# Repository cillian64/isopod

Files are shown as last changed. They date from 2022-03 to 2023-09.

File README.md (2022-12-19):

# ISOPOD

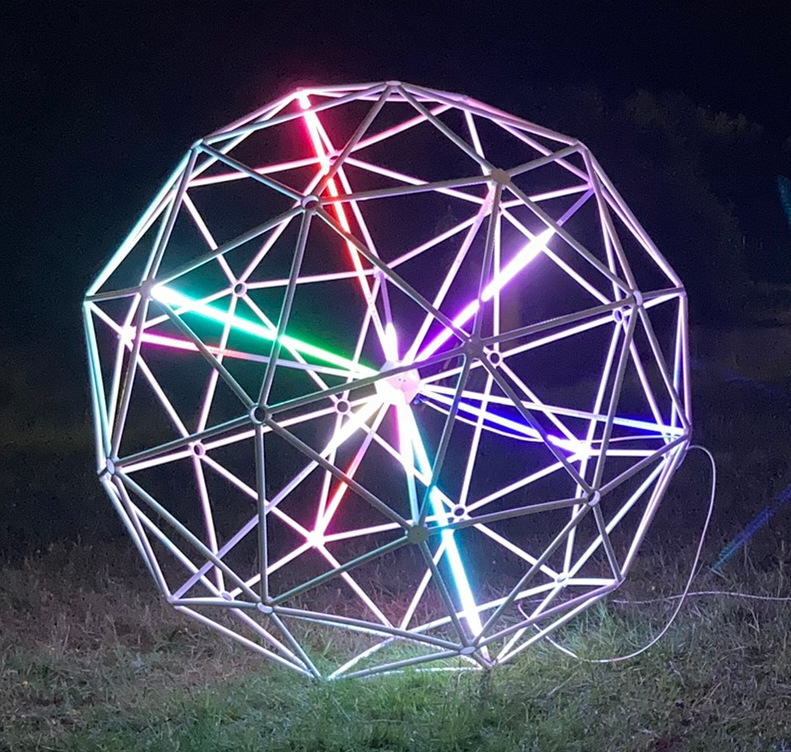
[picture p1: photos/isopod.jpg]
A photo of ISOPOD with a colourful pattern


ISOPOD is a mobile interactive LED sculpture based on a 2.1m geodesic
isocahedron.  It was displayed at [EMF 2022](https://www.emfcamp.org/).

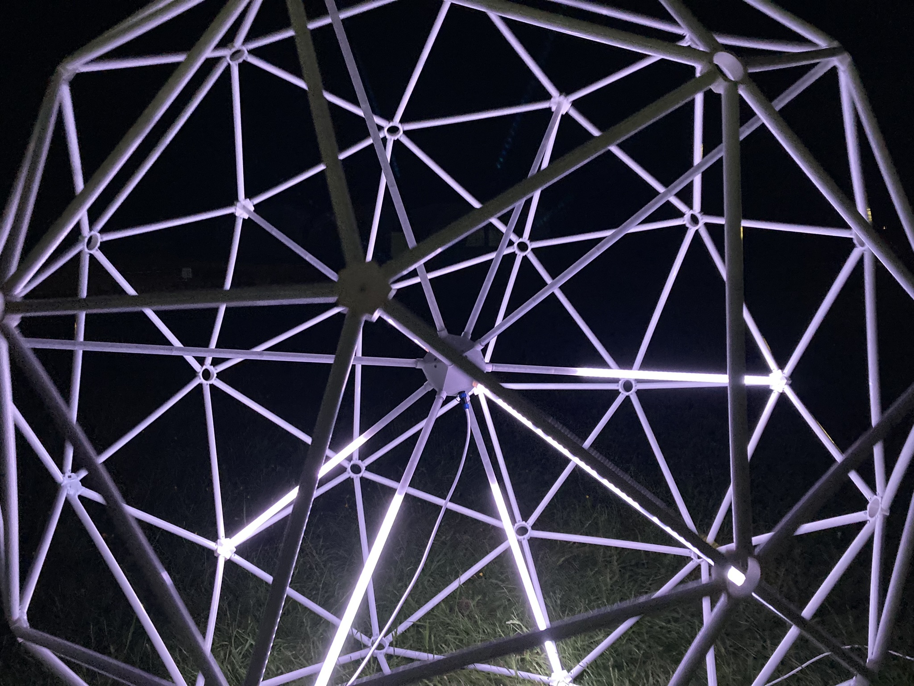
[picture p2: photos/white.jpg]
A close-up photo of ISOPOD's structure


The outer shell is a 2V geodesic isocahedron made from custom-designed 3d
printed hubs and plastic water pipe.  The core is a regular icosahedron.  12
LED tubes connect to the core's vertices, each made from frosted acrylic tube
and containing a WS2812b addressable LED strip.

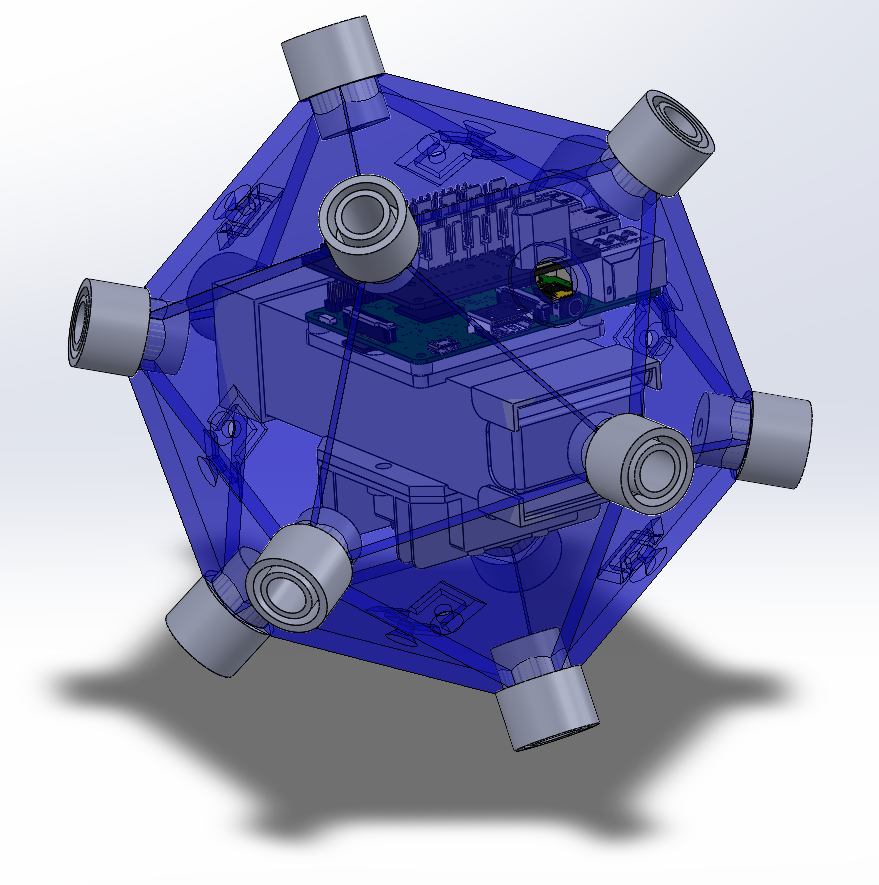
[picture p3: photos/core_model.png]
A 3d model of the ISOPOD core and components


The core contains a battery, control electronics, and DC-DC converters.  ISOPOD
is controlled by a Raspberry Pi running software written in Rust.  A custom PCB
mounted on the Pi connects to the battery, DC-DC converters, and LED strips and
adds a battery fuel gauge, GPS module, and 9-axis IMU (accelerometer,
gyroscope, and magnetometer).

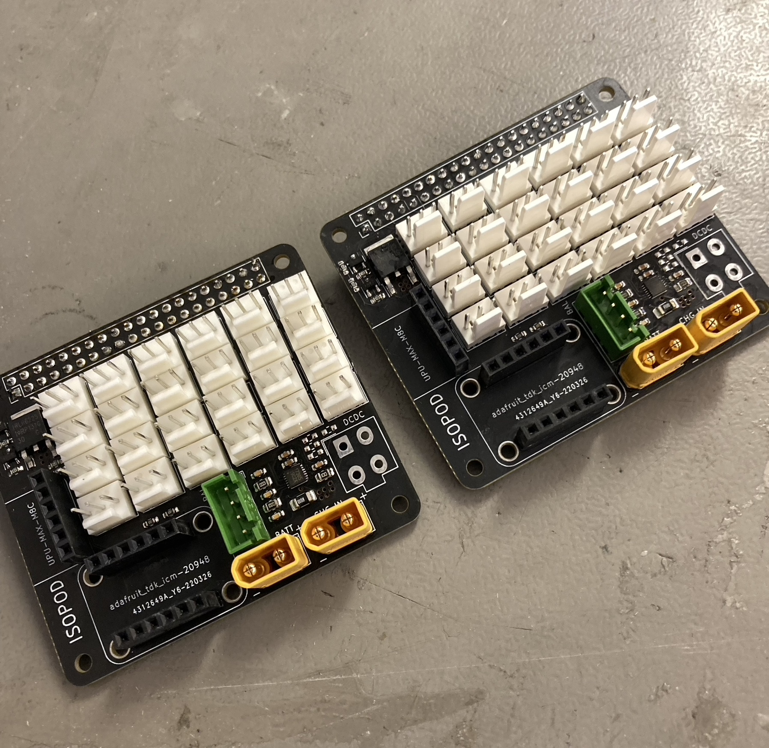
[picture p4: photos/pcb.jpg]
A photo of the ISOPOD PCBs


ISOPOD was displayed at EMF 2022 with a tether cable (to extend battery life
and avoid it rolling downhill into the lake) but is designed to be totally
wireless, reporting its position and status over Wi-Fi to a backend server.

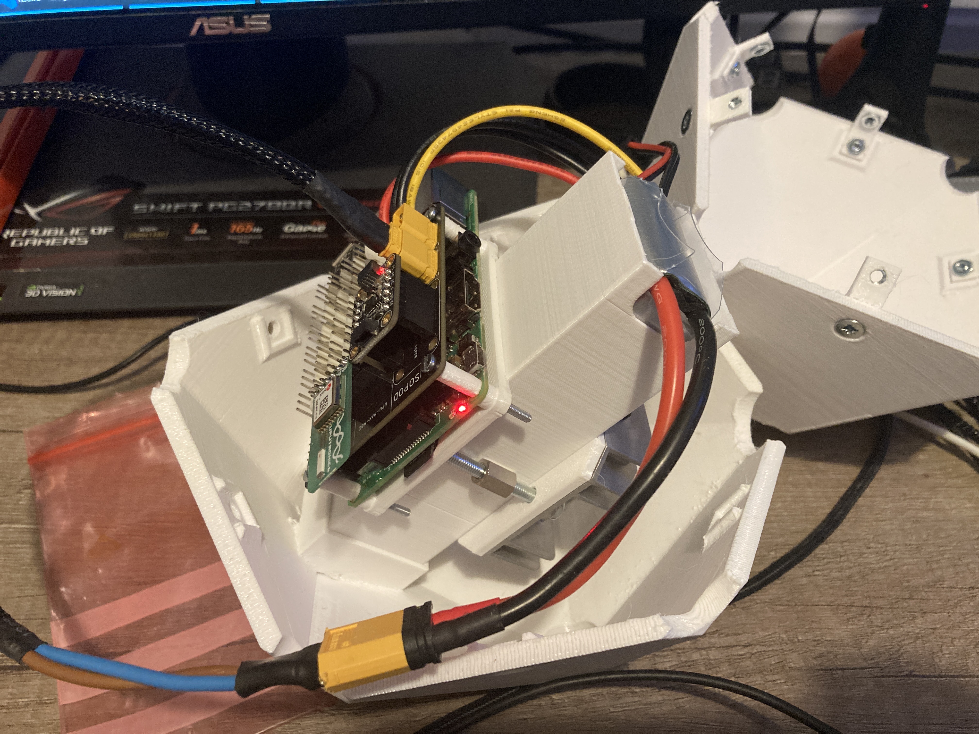
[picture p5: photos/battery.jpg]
A photo of the battery connection


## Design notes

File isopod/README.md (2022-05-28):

# ISOPOD firmware

This is the firmware for Isopod.

## Simulator / visualiser
Normally the software is built to run on the raspberry pi hardware using the
`build_and_remote_run.sh` script.  However for pattern development it's
possible to run the software on a PC (with no sensor or GPS or LED access)
and view the LED status using the web visualiser.  To run the software on
a PC, run, on linux:

```cargo run --target=x86_64-unknown-linux-gnu --no-default-features --bin isopod```

Or on MacOS:

```cargo run --target=x86_64-apple-darwin --no-default-features --bin isopod```

Then open the [sim/sim.html](sim/sim.html) file in your browser.  The
visualiser can be connected to either the actual raspberry pi or to the local
simulator by toggling the "local sim" / "hardware" buttons in the top left
corner.

## Architecture
### Firmware functions
* Collect location data from GPS peripheral over UART
* Collect movement/orientation data from IMU over I2C
* Collect battery level from fuel gauge over I2C
* Control addressable LEDs via PWM and GPIO
* Report location to a remote server over HTTPS over Wi-Fi

### LED control algorithm
The LED-control logic is roughly as follows:
* If the battery level is low then do a low-power pattern:
  * Every three seconds flash all LEDs briefly red and otherwise off.
* Otherwise, if we are currently moving, illuminate all the LEDs with a hue
  which depends on current orientation, full saturation, and a value depending
  on gyro rate.
* Otherwise, if we are currently stationary but have moved within the past few
  minutes, do a pattern depending on our current orientation.  Ideas:
  * Smooth rainbow colour fading
  * Random sparkling
  * Radial rainfall with colour spots mixed in
  * TODO: more ideas here
* Otherwise, if we have not moved in a couple of minutes then do the idle
  pattern:
  * Every second, pulse red from the centre out

### Architecture
The firmware is architected roughly as follows:
* GPS, IMU, and battery level data are collected by separate threads
* Their data is written into shared structures which are protected by mutexes
* The main thread implements application logic - it reads from the sensor
  structures and writes to the LED control structure.
* An LED control thread determines the desired LED state, and writes to the
  PWM and GPIO peripherals to control the LEDs.
* A location reporting thread periodically reports the location over HTTPS
  over Wi-Fi.

## Setup

Install rust with default setup:

`curl --proto '=https' --tlsv1.2 -sSf https://sh.rustup.rs | sh`

Install some more things, some only required for cross-compilation

sudo apt install llvm build-essential gcc-arm-linux-gnueabihf libclang-dev gcc-multilib

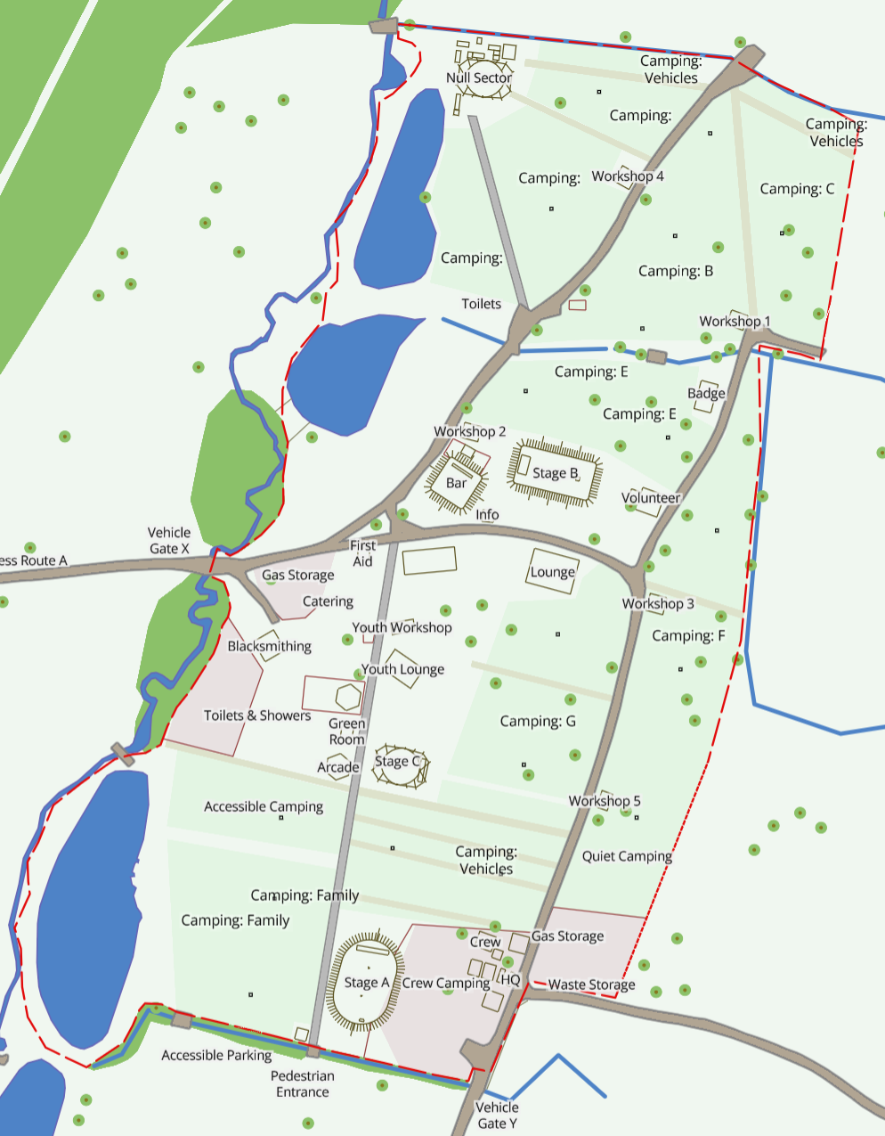
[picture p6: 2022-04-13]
backend/emf_base_map.png

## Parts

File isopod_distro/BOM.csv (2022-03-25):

Comment | Designator | Footprint | LCSC | Qty/board | Qty
BAL | J29 | JST_XH_B4B-XH-AM_1x04_P2.50mm_Vertical | C594233 | 1 | 2
Raspberry_Pi_2_3 | J30 | PinHeader_2x20_P2.54mm_Vertical | C132132 | 1 | 2
100n | C4 | C_0603_1608Metric_Pad1.08x0.95mm_HandSolder | C14663 | 1 | 5
0.01R | R4 | R_1206_3216Metric_Pad1.30x1.75mm_HandSolder | C154635 | 1 | 5
1n | C3,C5,C6 | C_0603_1608Metric_Pad1.08x0.95mm_HandSolder | C1588 | 3 | 10
470n | C1,C2 | C_0603_1608Metric_Pad1.08x0.95mm_HandSolder | C1623 | 2 | 10
100 | R2,R3 | R_0805_2012Metric_Pad1.20x1.40mm_HandSolder | C17408 | 2 | 10
10 | R1 | R_0805_2012Metric_Pad1.20x1.40mm_HandSolder | C17734 | 1 | 5
150 | R7,R8 | R_0603_1608Metric_Pad0.98x0.95mm_HandSolder | C22808 | 2 | 10
2R2 | R5 | R_0603_1608Metric_Pad0.98x0.95mm_HandSolder | C22939 | 1 | 5
10k | R10,R11,R12,R6,R9 | R_0603_1608Metric_Pad0.98x0.95mm_HandSolder | C23192 | 5 | 15
MAX17205 | U1 | TDFN-14-1EP_3x3mm_P0.4mm_EP1.78x2.35mm | C401140 | 1 | 3
BSS138 | Q2,Q3 | SOT-23 | C75547 | 2 | 10
DCDC | J8 | Molex_Mini-Fit_Jr_5566-04A_2x02_P4.20mm_Vertical | C47233 | 1 | 5
IN 1 | J10,J11,J12,J13,J14,J15,J17,J18,J19,J2,J20,J21,J22,J23,J24,J25,J26,J27,J28,J3,J4,J5,J6,J7 | Molex_KK-254_AE-6410-03A_1x03_P2.54mm_Vertical | C706936 | 24 | 24
CHG_IN | J1,J16 | AMASS_XT30U-M_1x02_P5.0mm_Vertical | C99101 | 2 | 2

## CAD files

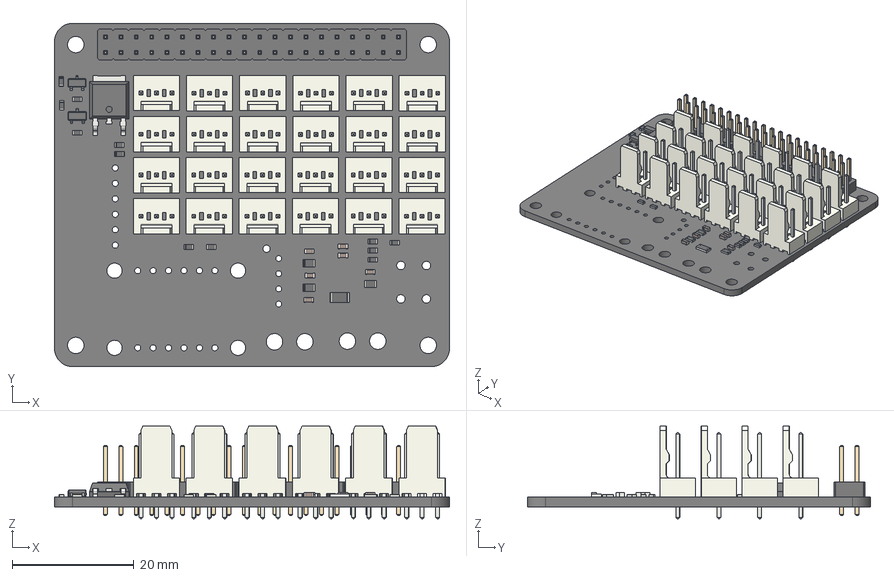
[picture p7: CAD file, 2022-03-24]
isopod_distro/isopod_distro.step
65.0 x 56.5 x 15.3 mm
Pcb_4663
Q2_SOT_23_13de3de3c2ef x 2
R11_R_0603_1608Metric_2da430bc9cf8 x 12
C1_C_0603_1608Metric_94d6544a8366 x 6
J23_Molex_AE_6410_03A_57582ce10efd x 24
J30_PinHeader_2x20_P254mm_Vertical_b2ee337b9778
R4_R_1206_3216Metric_e61873b6a125
R1_R_0805_2012Metric_dd68c0426109 x 3
Q1_TO_252_2_08bba05e86ff

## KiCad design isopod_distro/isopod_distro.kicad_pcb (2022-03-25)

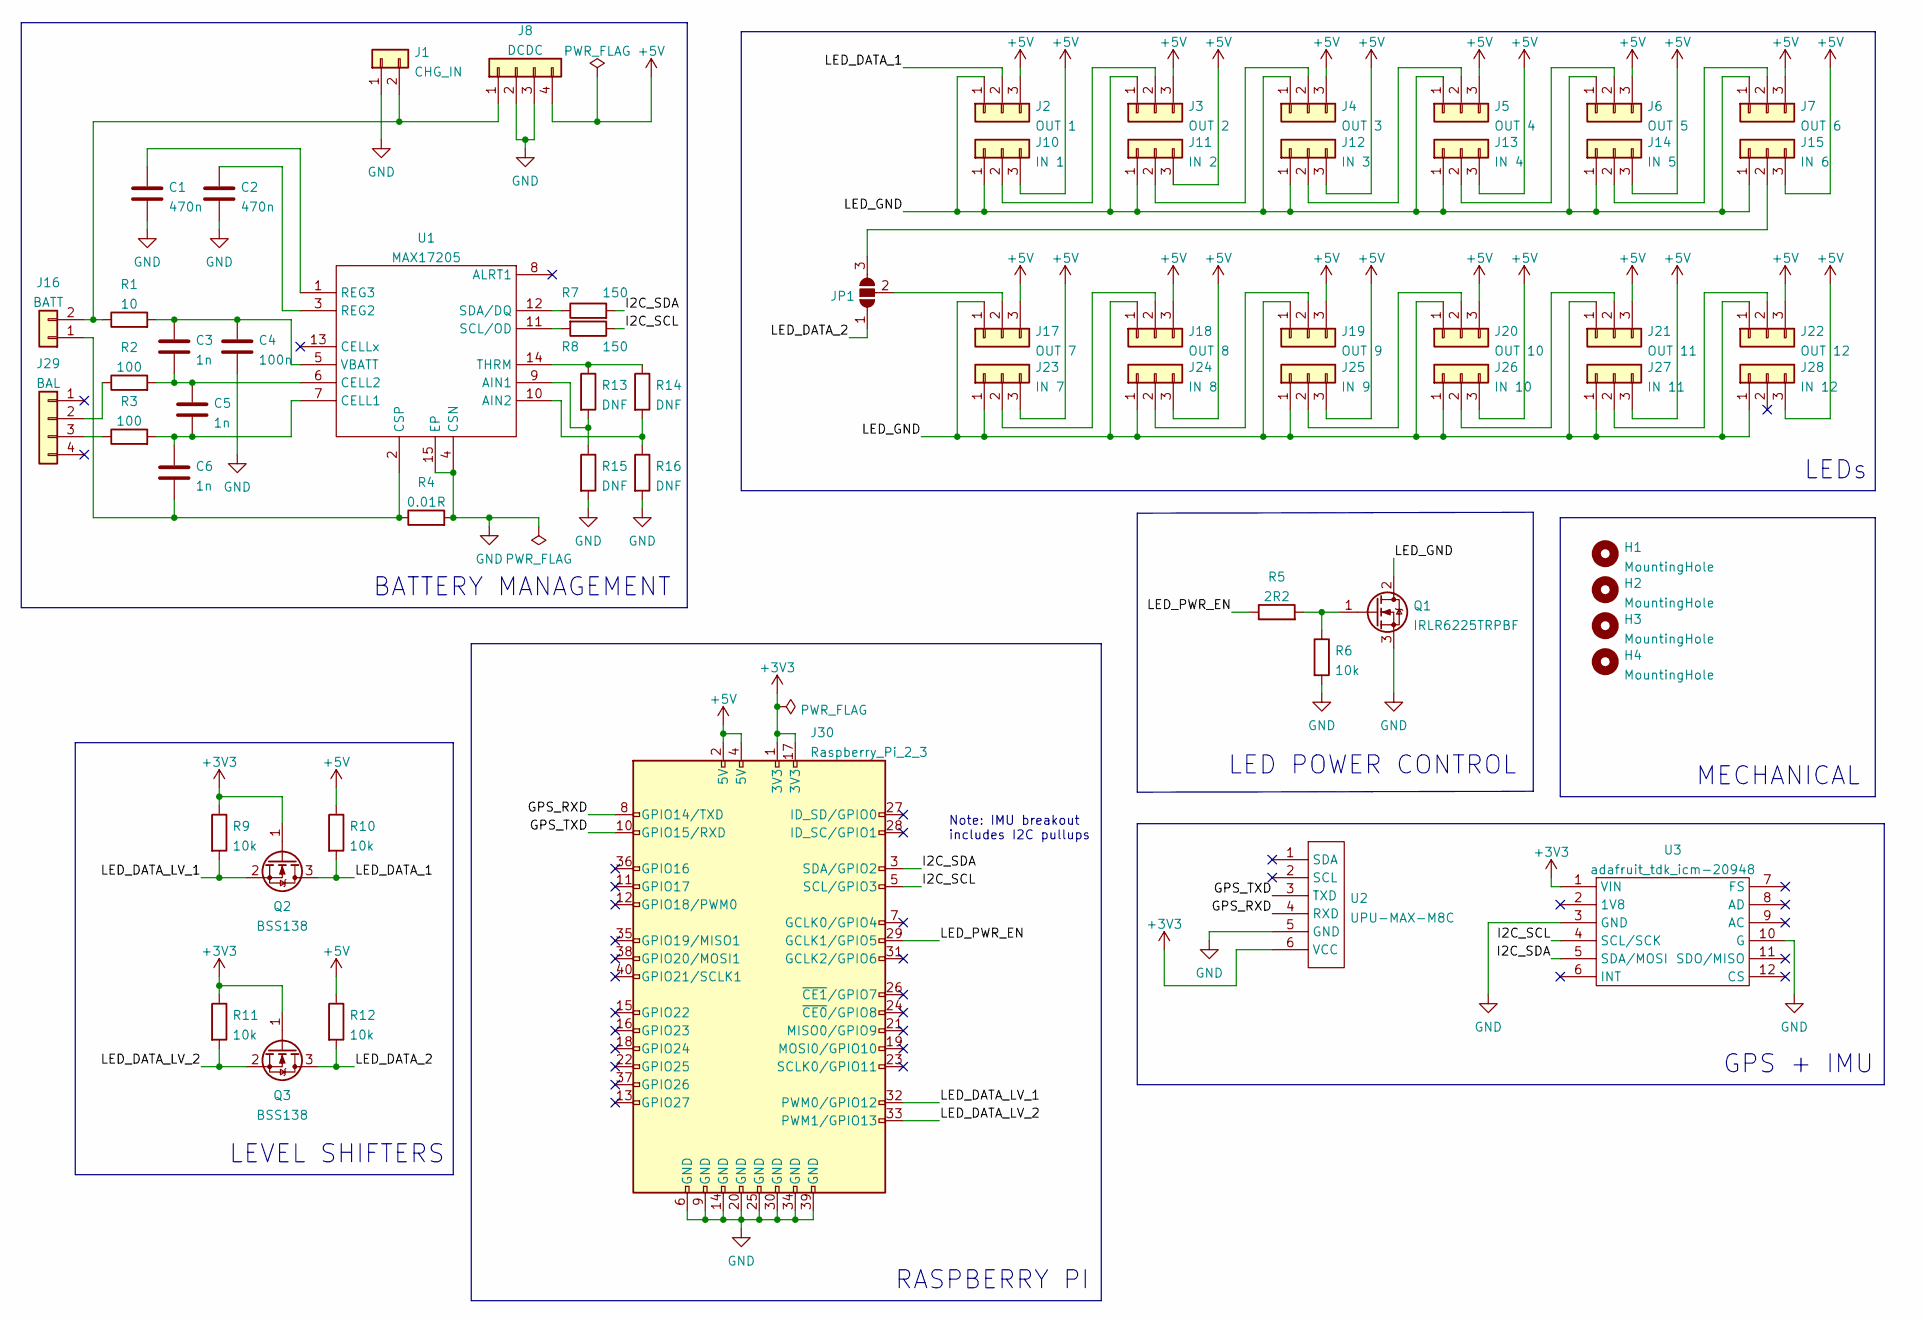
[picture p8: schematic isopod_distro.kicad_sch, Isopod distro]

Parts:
C1, C2: 470n; C_0603_1608Metric_Pad1.08x0.95mm_HandSolder
C3, C5, C6: 1n; C_0603_1608Metric_Pad1.08x0.95mm_HandSolder
C4: 100n; C_0603_1608Metric_Pad1.08x0.95mm_HandSolder
H1, H2, H3, H4: MountingHole; MountingHole_2.7mm
J1: CHG_IN; AMASS_XT30U-M_1x02_P5.0mm_Vertical
J2: OUT 1; Molex_KK-254_AE-6410-03A_1x03_P2.54mm_Vertical
J3: OUT 2; Molex_KK-254_AE-6410-03A_1x03_P2.54mm_Vertical
J4: OUT 3; Molex_KK-254_AE-6410-03A_1x03_P2.54mm_Vertical
J5: OUT 4; Molex_KK-254_AE-6410-03A_1x03_P2.54mm_Vertical
J6: OUT 5; Molex_KK-254_AE-6410-03A_1x03_P2.54mm_Vertical
J7: OUT 6; Molex_KK-254_AE-6410-03A_1x03_P2.54mm_Vertical
J8: DCDC; Molex_Mini-Fit_Jr_5566-04A_2x02_P4.20mm_Vertical
J10: IN 1; Molex_KK-254_AE-6410-03A_1x03_P2.54mm_Vertical
J11: IN 2; Molex_KK-254_AE-6410-03A_1x03_P2.54mm_Vertical
J12: IN 3; Molex_KK-254_AE-6410-03A_1x03_P2.54mm_Vertical
J13: IN 4; Molex_KK-254_AE-6410-03A_1x03_P2.54mm_Vertical
J14: IN 5; Molex_KK-254_AE-6410-03A_1x03_P2.54mm_Vertical
J15: IN 6; Molex_KK-254_AE-6410-03A_1x03_P2.54mm_Vertical
J16: BATT; AMASS_XT30U-M_1x02_P5.0mm_Vertical
J17: OUT 7; Molex_KK-254_AE-6410-03A_1x03_P2.54mm_Vertical
J18: OUT 8; Molex_KK-254_AE-6410-03A_1x03_P2.54mm_Vertical
J19: OUT 9; Molex_KK-254_AE-6410-03A_1x03_P2.54mm_Vertical
J20: OUT 10; Molex_KK-254_AE-6410-03A_1x03_P2.54mm_Vertical
J21: OUT 11; Molex_KK-254_AE-6410-03A_1x03_P2.54mm_Vertical
J22: OUT 12; Molex_KK-254_AE-6410-03A_1x03_P2.54mm_Vertical
J23: IN 7; Molex_KK-254_AE-6410-03A_1x03_P2.54mm_Vertical
J24: IN 8; Molex_KK-254_AE-6410-03A_1x03_P2.54mm_Vertical
J25: IN 9; Molex_KK-254_AE-6410-03A_1x03_P2.54mm_Vertical
J26: IN 10; Molex_KK-254_AE-6410-03A_1x03_P2.54mm_Vertical
J27: IN 11; Molex_KK-254_AE-6410-03A_1x03_P2.54mm_Vertical
J28: IN 12; Molex_KK-254_AE-6410-03A_1x03_P2.54mm_Vertical
J29: BAL; JST_XH_B4B-XH-AM_1x04_P2.50mm_Vertical
J30: Raspberry_Pi_2_3; PinHeader_2x20_P2.54mm_Vertical
JP1: SolderJumper_3_Open; SolderJumper-3_P1.3mm_Bridged12_RoundedPad1.0x1.5mm
Q1: IRLR6225TRPBF; TO-252-2; Farnell 2726021
Q2, Q3: BSS138; SOT-23
R1: 10; R_0805_2012Metric_Pad1.20x1.40mm_HandSolder
R2, R3: 100; R_0805_2012Metric_Pad1.20x1.40mm_HandSolder
R4: 0.01R; R_1206_3216Metric_Pad1.30x1.75mm_HandSolder
R5: 2R2; R_0603_1608Metric_Pad0.98x0.95mm_HandSolder
R6, R9, R10, R11, R12: 10k; R_0603_1608Metric_Pad0.98x0.95mm_HandSolder
R7, R8: 150; R_0603_1608Metric_Pad0.98x0.95mm_HandSolder
R13, R14, R15, R16: DNF; R_0603_1608Metric_Pad0.98x0.95mm_HandSolder
U1: MAX17205; TDFN-14-1EP_3x3mm_P0.4mm_EP1.78x2.35mm; Farnell 3404585
U2: UPU-MAX-M8C; upu-max-m8c
U3: adafruit_tdk_icm-20948; adafruit-tdk-icm-20948

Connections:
+3V3: J30.1 (3V3), J30.17 (3V3), Q2.1 (G), Q3.1 (G), R9.1, R11.1, U2.6 (VCC), U3.1 (VIN)
+5V: J2.3, J3.3, J4.3, J5.3, J6.3, J7.3, J8.4, J10.3, J11.3, J12.3, J13.3, J14.3, J15.3, J17.3, J18.3, J19.3, J20.3, J21.3, J22.3, J23.3, J24.3, J25.3, J26.3, J27.3, J28.3, J30.2 (5V), J30.4 (5V), R10.1, R12.1
/GPS_RXD: J30.8 (GPIO14/TXD), U2.4 (RXD)
/GPS_TXD: J30.10 (GPIO15/RXD), U2.3 (TXD)
/I2C_SCL: J30.5 (SCL/GPIO3), R8.1, U3.4 (SCL/SCK)
/I2C_SDA: J30.3 (SDA/GPIO2), R7.2, U3.5 (SDA/MOSI)
/LED_DATA_1: J2.2, Q2.3 (D), R10.2
/LED_DATA_2: JP1.1 (A), Q3.3 (D), R12.2
/LED_DATA_LV_1: J30.32 (PWM0/GPIO12), Q2.2 (S), R9.2
/LED_DATA_LV_2: J30.33 (PWM1/GPIO13), Q3.2 (S), R11.2
/LED_GND: J2.1, J3.1, J4.1, J5.1, J6.1, J7.1, J10.1, J11.1, J12.1, J13.1, J14.1, J15.1, J17.1, J18.1, J19.1, J20.1, J21.1, J22.1, J23.1, J24.1, J25.1, J26.1, J27.1, J28.1, Q1.2 (D)
/LED_PWR_EN: J30.29 (GCLK1/GPIO5), R5.1
GND: C1.2, C2.2, C4.2, J1.1, J8.2, J8.3, J30.6 (GND), J30.9 (GND), J30.14 (GND), J30.20 (GND), J30.25 (GND), J30.30 (GND), J30.34 (GND), J30.39 (GND), Q1.3 (S), R4.2, R6.2, R15.2, R16.2, U1.4 (CSN), U1.15 (EP), U2.5 (GND), U3.3 (GND), U3.10 (G)
unnamed: C1.1, U1.1 (REG3)
unnamed: C2.1, U1.3 (REG2)
unnamed: C3.1, C4.1, R1.2, U1.5 (VBATT)
unnamed: C3.2, C5.1, R2.2, U1.6 (CELL2)
unnamed: C5.2, C6.1, R3.2, U1.7 (CELL1)
unnamed: C6.2, J16.1, R4.1, U1.2 (CSP)
unnamed: J1.2, J8.1, J16.2, R1.1
unnamed: J3.2, J10.2
unnamed: J4.2, J11.2
unnamed: J5.2, J12.2
unnamed: J6.2, J13.2
unnamed: J7.2, J14.2
unnamed: J15.2, JP1.3 (B)
unnamed: J17.2, JP1.2 (C)
unnamed: J18.2, J23.2
unnamed: J19.2, J24.2
unnamed: J20.2, J25.2
unnamed: J21.2, J26.2
unnamed: J22.2, J27.2
unnamed: J29.2, R2.1
unnamed: J29.3, R3.1
unnamed: Q1.1 (G), R5.2, R6.1
unnamed: R7.1, U1.12 (SDA/DQ)
unnamed: R8.2, U1.11 (SCL/OD)
unnamed: R13.1, R14.1, U1.14 (THRM)
unnamed: R13.2, R15.1, U1.9 (AIN1)
unnamed: R14.2, R16.1, U1.10 (AIN2)

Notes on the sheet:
LED POWER CONTROL
BATTERY MANAGEMENT
LEVEL SHIFTERS
LEDs
MECHANICAL
GPS + IMU
RASPBERRY PI
Note: IMU breakout includes I2C pullups

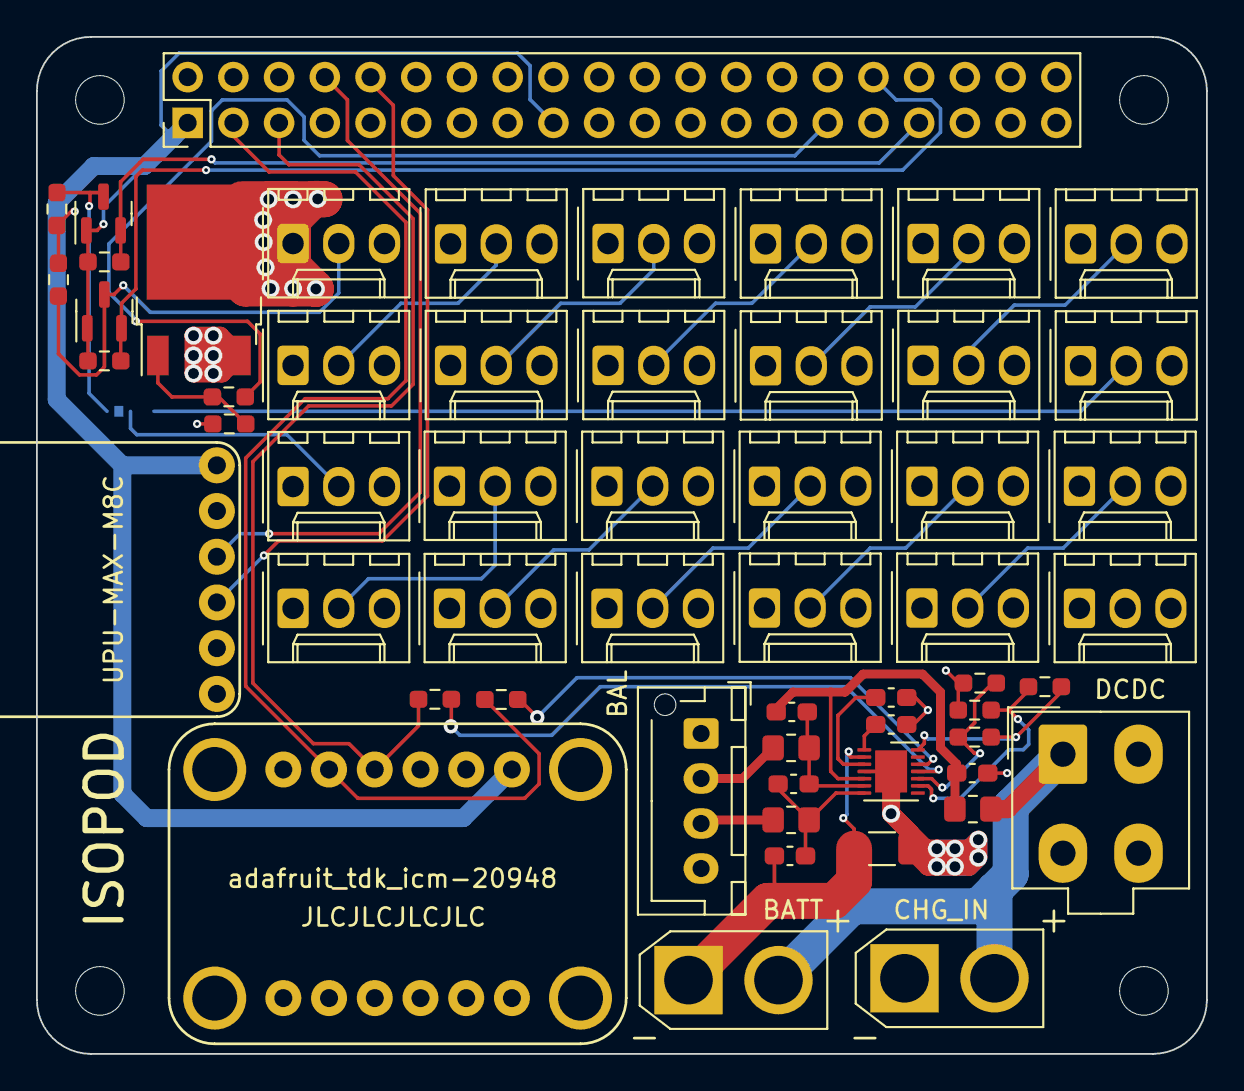
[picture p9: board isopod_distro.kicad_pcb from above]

Board: 4 copper layers, 65.0 x 56.5 mm, 62 parts (1 on the bottom side), 40 nets.

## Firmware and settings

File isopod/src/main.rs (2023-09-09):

//! Initialises and starts up worker threads to do the actual work.

use anyhow::Result;
use config::Config;
use lazy_static::lazy_static;
#[cfg(feature = "hardware")]
use rppal::gpio::Gpio;
#[cfg(feature = "hardware")]
use rppal::i2c::I2c;
#[cfg(feature = "hardware")]
use std::fs::File;
#[cfg(feature = "hardware")]
use std::sync::Arc;
use std::thread;
use std::time;

mod common_structs;
#[cfg(feature = "hardware")]
mod gps;
#[cfg(feature = "hardware")]
mod i2c;
#[cfg(feature = "hardware")]
mod led;
mod pattern_manager;
mod patterns;
#[cfg(feature = "hardware")]
mod reporter;
mod temperature;
mod control_server;
#[cfg(not(feature = "hardware"))]
use common_structs::ImuReadings;

pub const LEDS_PER_SPINE: usize = 59;
pub const SPINES: usize = 12;

lazy_static! {
    static ref SETTINGS: Config = Config::builder()
        .add_source(config::File::with_name("settings"))
        .build()
        .unwrap();
}

// If bluetooth is enabled then the raspberry pi serial port is
// /dev/ttyS0.  If bluetooth is disabled then /dev/ttyAMA0 is used.
#[cfg(feature = "hardware")]
const SERIAL_PORT: &str = "/dev/ttyS0";

#[cfg(feature = "hardware")]
fn main() -> Result<()> {
    println!("Hello, world!");

    println!("Setting up raw peripherals...");
    println!("Setting up GPIO...");
    let gpio = Gpio::new()?;
    println!("Setting up I2C...");
    let i2c = I2c::new()?;
    println!("Setting up GPS...");
    let file = File::open(SERIAL_PORT)?;
    let reader = std::io::BufReader::new(file);
    println!("Peripherals initialised okay!");

    println!("Setting up peripheral controllers...");
    println!("Setting up I2C peripherals controller...");
    let i2cperiphs = Arc::new(i2c::I2cPeriphs::new(i2c));
    println!("Setting up LED controller...");
    let mut led = led::Led::new(gpio);
    println!("Setting up GPS controller...");
    let gps = Arc::new(gps::Gps::new(reader));
    println!("Peripheral drivers initialised okay!");

    if SETTINGS.get("do_startup_tests")? {
        println!("Doing start-up tests...");
        gps.test()?;
        led.test()?;
        i2cperiphs.test()?;
        println!("Start-up tests look good!");
    } else {
        println!("Skipping start-up tests.");
    }

    println!("Starting worker threads...");
    led.start_thread();
    i2cperiphs.clone().start_thread();
    gps.clone().start_thread();
    let mut reporter = reporter::Reporter::new();

    control_server::start_server();
    println!("Worker threads started.");

    let mut pattern_manager = pattern_manager::PatternManager::new();

    let delay_ms = 1000 / SETTINGS.get::<u64>("fps")?;

    let mut last_report = time::Instant::now();
    let report_interval = SETTINGS.get::<u64>("reporter_interval")?;

    loop {
        // Read latest sensor values
        let gps_fix = gps.get();
        let imu_readings = i2cperiphs.get_imu();
        let battery_readings = i2cperiphs.get_battery();

        // Step pattern and update LEDs
        let led_state = pattern_manager.step(&gps_fix, &imu_readings);
        led.led_update(led_state)?;

        // Send a report if necessary
        let now = time::Instant::now();
        if report_interval > 0 && (now - last_report).as_secs() > report_interval {
            last_report = now;
            // Ignore report errors
            let _res = reporter.send(gps_fix, battery_readings);
        }

        // Sleep until time for the next pattern step
        thread::sleep(time::Duration::from_millis(delay_ms));
    }
}

#[cfg(not(feature = "hardware"))]
fn main() -> Result<()> {
    println!("Hello, world!");
    println!("Simulator mode: skipping setup and self-tests");

    println!("Starting worker threads...");
    // In simulator mode, always enable ws server regardless of config
    let ws = ws_server::WsServer::start_server();
    println!("Worker threads started.");

    let mut pattern_manager = pattern_manager::PatternManager::new();

    let delay_ms = 1000 / SETTINGS.get::<u64>("fps")?;

    loop {
        // Mock up sensor values
        let gps_fix = None;
        let imu_readings = ImuReadings::default();

        // Step pattern and update LEDs
        let led_state = pattern_manager.step(&gps_fix, &imu_readings);
        ws.led_update(led_state)?;

        // Sleep until time for the next pattern step
        thread::sleep(time::Duration::from_millis(delay_ms));
    }
}

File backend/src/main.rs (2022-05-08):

use warp::Filter;
use serde_derive::{Deserialize, Serialize};

#[derive(Debug, Deserialize, Serialize)]
struct Packet {
    long: f64,
    lat: f64,
    alt: f32,
    time: String,
    sats: usize,
    voltage: f32,
    current: f32,
    soc: f32,
    temp: String,
}

#[tokio::main]
async fn main() {
    let isopod = warp::post()
        .and(warp::path("isopod"))
        // Only accept bodies smaller than 16kb
        .and(warp::body::content_length_limit(1024 * 16))
        .and(warp::body::json())
        .map(|packet: Packet| {
            println!("Rx: {:#?}", packet);
            println!("https://maps.google.com/?q={},{}", packet.lat, packet.long);
            println!("");
            warp::reply()
        });

    warp::serve(isopod).run(([0, 0, 0, 0], 1309)).await

}

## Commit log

2022-02-13 Rough draft of distro board schematic
    [isopod_distro.kicad_pcb, isopod_distro.kicad_sch]
2022-02-19 First draft of schematic and pcb placement
    Finish first draft of schematic:
    * Replace relay with hexFET switch
    * Replace battery monitoring tap with fuel gauge / balance IC
    * Fill in various values
    * Pi pin assigments
    * Footprint assignments
    * Except for the power resistors around the fuel gauge
    PCB:
    * Draw Pi HAT PCB outline and place expansion header
    * Rough placement of most components
    [isopod_distro.kicad_pcb, isopod_distro.kicad_sch]
2022-02-20 Assign footprints for fuel gauge resistors
    [isopod_distro.kicad_pcb, isopod_distro.kicad_sch]
2022-02-20 Start routing PCB
    [isopod_distro.kicad_pcb]
2022-02-25 SW: Basic rust peripheral demo
    * Add the beginnings of the rust software
    * Basic peripheral test program which tests the IMU and GPS modules (and
    therefore the UART and I2C interfaces).
2022-02-27 Add STEP file of the PCB so far
    Use FreeCAD's KiCAD-stepup converter to convert the buildin models' VRML
    to STEP. In theory I could just change it to use the STEP versions of
    the models but it's quicker to just use the FreeCAD converter
    [isopod_distro.step]
2022-03-05 3-pin connectors for LED return, reroute
    * Use 3-pin connectors for LED return so we can supply power at both
    ends of the LED strip
    * Juggle placement of the PCB again
    * First draft of PCB routing
    [isopod_distro.kicad_pcb, isopod_distro.kicad_sch]
2022-03-06 Swap out batt/charge and DC-DC connectors
    Use XT30 for battery and charge connectors and MOLEX mini-fit jr 4-way
    for the DC-DC converter connection
    [isopod_distro.kicad_pcb, isopod_distro.kicad_sch]
2022-03-19 Final schematic checks
    * Add some DNF resistors for the fuel cell in case its temperature
    sensing can't be disabled
    * Add some series resistors on I2C because the appnote says so
    [isopod_distro.kicad_sch]
2022-03-19 Update PCB with schematic changes
    Add the new DNF resistors
    [isopod_distro.kicad_pcb]
2022-03-21 DRC fixes, further refinement
    [isopod_distro.kicad_pcb]
2022-03-24 PCB silkscreen
    Make the PCB silkscreen look neat: Remove most component references, add
    a few values where appropriate, label connectors and pinouts, board name
    etc.
    [isopod_distro.kicad_pcb, isopod_distro.kicad_sch]
2022-03-24 Update PCB STEP model
    [isopod_distro.step]
2022-03-24 DRC fixes/exclusions
    [isopod_distro.kicad_pcb]
2022-03-24 Add JLC order marking, BOM, gerbs
    * Add JLCJLCJLCJLC location for order number
    * Add JLC/LCSC BOM database
    * Add finished gerbers
    [isopod_distro-CuBottom.gbr, isopod_distro-CuIn1.gbr, isopod_distro-CuIn2.gbr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]
2022-03-25 Final BOM
    [BOM.csv, isopod_distro.kicad_pcb]
2022-04-09 LED working proof of concept
    * Remove all the unimplemented macro usage so I can test things more
    * Put sleeps in threads so they don't hardloop
    * Basic LED test proof of concept
    * Update serial port for newer raspian
2022-04-09 Rainbow LEDs at the same time as UART+I2C
    Check for DMA collisions by smoothly fading LEDs at the same time as
    reading the GPS data over UART and regularly polling the I2C IMU sensor.
    [i2c.rs, led.rs]
2022-04-09 Proof-of-concept location reporter
    * Store the GPS fix each time we get a fix
    * Periodically send the fix to the reporter thread
    * Reporter thread JSONifies the fix and sends it over HTTPS to the
    backend
    [i2c.rs, main.rs]
2022-04-09 Basic proof-of-concept reporter server
    * Receives reports
    * Deserializes the JSON into a nice Fix struct
    * Prints it out.
    [main.rs]
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2022-04-15 Add basic websocket server
    This will be used to connect to the web-based visualiser and relay LED
    state to it
2022-04-15 Prototype: Send LED states from main thread
    Generate LED pattern in main thread and send it to the LED and WS
    threads. This doesn't actually work currently, is a WIP.
    [led.rs, main.rs]
2022-04-16 Ignore WS channel errors, add build script
    * Ignore mysterious errors from the tokio broadcast channel used for WS
    LED updates
    * Disable startup tests for now
    * Add script to cross-compile software, SCP it over to beacon, and run
    it.
    [main.rs]
2022-04-16 First draft of pattern trait interface
    * Add the Pattern trait to be used for patterns
    * Add a Zoom pattern as an example of using this
    * Do a little bit of other renaming/cleanup:
    * Rename Fix to GpsFix
    * Add an ImuReadings struct for IMU readings
    [i2c.rs, main.rs, mod.rs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]
2022-04-16 Add units to GPS fix and accelerometer data
    [i2c.rs]
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2022-04-17 "shock" pattern: demo pattern depending on IMU
    Basic demonstrator pattern which illuminates all the LEDs if
    acceleration exceeds a certain threshold. Uses a moving average to
    ignore gravity or other constant offset.
2022-04-17 LED FPS improvement
    * Modify the LED channel reader to discard all but the latest message in
    the channel.
    * This means that if the LED renderer thread falls behind the pattern
    generator then we drop updates instead of falling behind and growing
    the channel buffer indefinitely.
    * This also means we get a warning message if we fall behind.
    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
2022-04-21 Name the threads
    Helps with profiling in htop and also debugging backtraces. Pity you
    can't seem to name the main thread.
2022-04-21 Move JSONifying to a new thread
    Previously JSONifying the LED data was done separately for each
    websocket handler. This took up 30% of a CPU core per websocket so is a
    lot of load if multiple websockets are connected. But we don't want to
    do this in led_update which would burden the main thread with this. So
    make a new JSONifier thread which receives LedUpdates from the main
    thread, turns them into JSON, then broadcasts them to all the websocket
    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
2022-04-21 Add config file
    Read a simple config file to determine some things so I don't have to
    keep recompiling to twiddle settings. Current settings:
    * FPS
    * Enable/disable websocket server
    * Enable/disable start-up tests
2022-04-22 Use a hashmap of function ptrs to store patterns
    This way means that we don't unnecessarily initialise all patterns at
    startup, and can more easily reinitialise a pattern when switching back
    to it for the second time.
2022-04-22 Format google maps link for backend fix reports
    [main.rs]
2022-04-26 Log battery status and report to backend
    Integrate the new MAX1720x crate to read the battery status from the
    fuel gauge IC, log the battery status, and report it to the backend
    server
2022-04-27 Allow simulator to run on PCs
    Add a rust "hardware" feature which you can disable to disable all of
    the peripherals and raspberry-pi specifics.
    When this feature is disabled all of the sensor values get stubbed out
    and the LED updates are only sent to the web visualiser. Also the
    reporter is disabled to minimise the spam the backend sees.
    Update the web visualiser to have button to decide whether it connects
    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
2022-05-08 Fixup previous commit for no-hardware sim mode
    Also cargo fmt
    [glitch.rs, led.rs, main.rs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]
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2022-05-21 Fix a camera control bug in visualiser
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2022-05-21 Add LED mapping
    Add a map from connector numbers on the PCB to spine positions on the
    icosahedron, stored in the config file. This means it doesn't matter
    which hole the LED cables go to so long as we write down the mapping.
    [led.rs, mod.rs]
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2022-05-22 Implement power limiter
    Work out how much power the LEDs will consume (based on some
    measurements and some approximations) and apply a limiter function so as
    to not exceed the power supply rating (too much).
    [led.rs, searchlight.rs]
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2022-05-27 Fix bug in vector norm function
    That is definitely not how you calculate the 2-norm of a vector...
    [common_structs.rs]
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2022-06-04 Jukebox mode
    Basic on a fixed timer with no shuffling or transitions
    [mod.rs]
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2023-04-08 Make glitch more intense
    [glitch.rs]
2023-07-23 Add frame-skip to starfield
    [starfield.rs]
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
